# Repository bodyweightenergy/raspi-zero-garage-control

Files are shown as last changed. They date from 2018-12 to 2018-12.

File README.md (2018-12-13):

# raspi-zero-garage-control (INCOMPLETE)

Garage Status Indicator/Controller, using a Raspberry Pi Zero W custom Bonnet, with Rust-based software stack.

## Hardware
KiCAD schematics & PCB layout are provided. PCB designed for 10mmx10mm cheap from EasyEDA/JLCPCB. 
Simply generate the GERBERs using KiCAD 5.0 or later, and order from them, and you'll get 20 copies of this Bonnet.

## Software
GPIO & HTTP stack use Rust. While compiling this on the Pi does work, it will take a long time, so setting up a development computer for cross-compiling is recommended.

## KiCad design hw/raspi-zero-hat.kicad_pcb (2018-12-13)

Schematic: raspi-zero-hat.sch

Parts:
D1, D2: LED; LED_1206_3216Metric_Pad1.42x1.75mm_HandSolder
J1: Screw_Terminal_01x02; TerminalBlock_Phoenix_PT-1,5-2-3.5-H_1x02_P3.50mm_Horizontal
J2: Screw_Terminal_01x03; TerminalBlock_Phoenix_PT-1,5-3-3.5-H_1x03_P3.50mm_Horizontal
K1: G5LE-1; Relay_SPDT_Omron-G5LE-1
MK1, MK2, MK3, MK4: M2.5; MountingHole_2.7mm_M2.5
P1: Conn_02x20_Odd_Even; PinSocket_2x20_P2.54mm_Vertical
Q1: MMBT3904; SOT-23
R1, R2: R; R_1206_3216Metric_Pad1.42x1.75mm_HandSolder

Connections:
+3V3: P1.1, P1.17
+5V: J1.1, P1.2, P1.4, Q1.3 (C)
/GPIO2(SDA1): P1.3
/GPIO3(SCL1): P1.5
/GPIO4(GCLK): P1.7
/GPIO5: P1.29
/GPIO6: P1.31
/GPIO7(SPI1_CE_N): P1.26
/GPIO8(SPI0_CE_N): P1.24
/GPIO9(SPI0_MISO): P1.21
/GPIO10(SPI0_MOSI): P1.19
/GPIO11(SPI0_SCK): P1.23
/GPIO12(PWM0): P1.32
/GPIO13(PWM1): P1.33
/GPIO15(RXD0): P1.10, Q1.1 (B)
/GPIO16: P1.36
/GPIO17(GEN0): P1.11
/GPIO18(GEN1)(PWM0): P1.12
/GPIO19(SPI1_MISO): P1.35
/GPIO20(SPI1_MOSI): P1.38
/GPIO21(SPI1_SCK): P1.40
/GPIO22(GEN3): P1.15
/GPIO23(GEN4): J1.2, P1.16
/GPIO24(GEN5): D1.2, P1.18
/GPIO25(GEN6): P1.22
/GPIO26: P1.37
/GPIO27(GEN2): P1.13
/ID_SC: P1.28
/ID_SD: P1.27
GND: K1.2, P1.6, P1.9, P1.14, P1.20, P1.25, P1.30, P1.34, P1.39, R1.2, R2.2
unnamed: D1.1, R1.1
unnamed: D2.1, R2.1
unnamed: D2.2, K1.5, Q1.2 (E)
unnamed: J2.1, K1.4
unnamed: J2.2, K1.1
unnamed: J2.3, K1.3

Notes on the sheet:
ID_SD and ID_SC PINS: These pins are reserved for HAT ID EEPROM. At boot time this I2C interface will be interrogated to look for an EEPROM that identifes the attached board and allows automagic setup of the GPIOs (and optionally, Linux drivers). DO NOT USE these pins for anything other than attach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
Mounting Holes

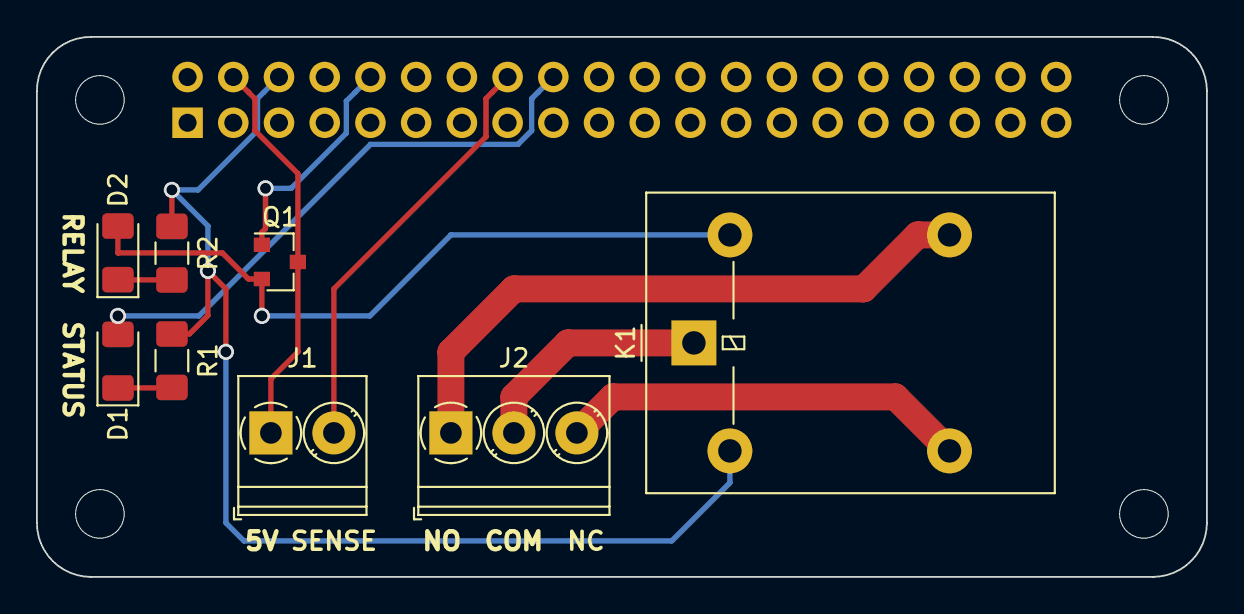
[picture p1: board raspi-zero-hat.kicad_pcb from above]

Board: 2 copper layers, 65.0 x 30.0 mm, 13 parts (1 on the bottom side), 12 nets.

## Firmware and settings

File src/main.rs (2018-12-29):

use rppal::gpio::{Gpio, Level, Mode};
use rppal::system::DeviceInfo;
use env_logger;
use actix;
use actix_web::{self, middleware, server, App, HttpRequest, HttpResponse};
use actix_web::middleware::identity::{CookieIdentityPolicy, IdentityService, RequestIdentity};

use std::sync::{Arc, Mutex};
use std::thread;
use std::thread::sleep;
use std::time::{self, Duration};
use std::fs::File;
use std::io::Write;

// pin numbers
const RELAY_LED: u8 = 15;
const STATUS_LED: u8 = 24;
const SENSE_PIN: u8 = 23;

struct AppState {
	gpio_ctrl: Arc<Mutex<Gpio>>
}

fn toggle(req: &HttpRequest<AppState>) -> HttpResponse {
	println!("{:?}", req);
	let gpio = req.state().gpio_ctrl.lock().unwrap();
	gpio.write(RELAY_LED, Level::High);
	gpio.write(STATUS_LED, Level::High);
	thread::sleep(Duration::from_secs(1));
	gpio.write(RELAY_LED, Level::Low);
	gpio.write(STATUS_LED, Level::Low);
	HttpResponse::Ok().body("Relay toggled")
}

fn sense(req: &HttpRequest<AppState>) -> HttpResponse {
	println!("{:?}", req);
	let gpio = req.state().gpio_ctrl.lock().unwrap();
	let sense_value = gpio.read(SENSE_PIN).unwrap();
	println!("Sense: {:?}", sense_value);
	HttpResponse::Ok().body(match sense_value {
		Level::High => "CLOSED",
		Level::Low => "OPEN"
	})
}

fn main() {
	println!("Garage Controller has started.");

	let device_info = DeviceInfo::new().unwrap();
	println!(
		"Model: {} (SoC: {})",
		device_info.model(),
		device_info.soc()
	);

	// Initialize Gpio
	let mut gpio = Gpio::new().unwrap();
	gpio.set_mode(RELAY_LED, Mode::Output);
	gpio.set_mode(STATUS_LED, Mode::Output);
	gpio.set_mode(SENSE_PIN, Mode::Input);

	let gpio_mutex = Arc::new(Mutex::new(gpio));
	let gpio_hb_clone = gpio_mutex.clone();

	// Start heartbeat LED
	let _hb_thread = thread::spawn(move || {
		let gpio = gpio_hb_clone;
		loop {
			{
				gpio.lock().unwrap().write(STATUS_LED, Level::High);
			}
			sleep(Duration::from_secs(1));
			{
				gpio.lock().unwrap().write(STATUS_LED, Level::Low);
			}
			sleep(Duration::from_secs(1));
		}
	});

	// Initialize web server
	::std::env::set_var("RUST_LOG", "actix_web=info");
	env_logger::init();
	let sys = actix::System::new("ws-example");

	server::new(move || {
		App::with_state(AppState {gpio_ctrl: gpio_mutex.clone()})
		.middleware(middleware::Logger::default())
		.middleware(IdentityService::new(
			CookieIdentityPolicy::new(&[0; 32])
			.name("auth-example")
			.secure(false)
		))
		.resource("/toggle", |r| r.f(toggle))
		.resource("/sense", |r| r.f(sense))
	}).bind("0.0.0.0:8888")
	.unwrap()
	.start();

	println!("Started HTTP server: 0.0.0.0:8888");
	let _ = sys.run();

	
}

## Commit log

2018-08-15 initial commit (standard size, no relay driver MOSFET)
    [raspi-zero-hat.kicad_pcb, raspi-zero-hat.sch]
2018-08-16 added NPN for relay drive. duplicated PCB w/ perforations.
    [raspi-zero-hat.kicad_pcb, raspi-zero-hat.sch]
2018-11-27 moved to hardware folder
    [raspi-zero-hat.kicad_pcb, raspi-zero-hat.sch]
2018-12-13 moved relay control pin to pin 10 (pin 8 was pulled up on boot, causing an unintended relay toggle).
    [raspi-zero-hat.kicad_pcb, raspi-zero-hat.sch]
2018-12-28 switched to actix-web, added toggle and sense methods
2018-12-29 added status LED heartbeat
